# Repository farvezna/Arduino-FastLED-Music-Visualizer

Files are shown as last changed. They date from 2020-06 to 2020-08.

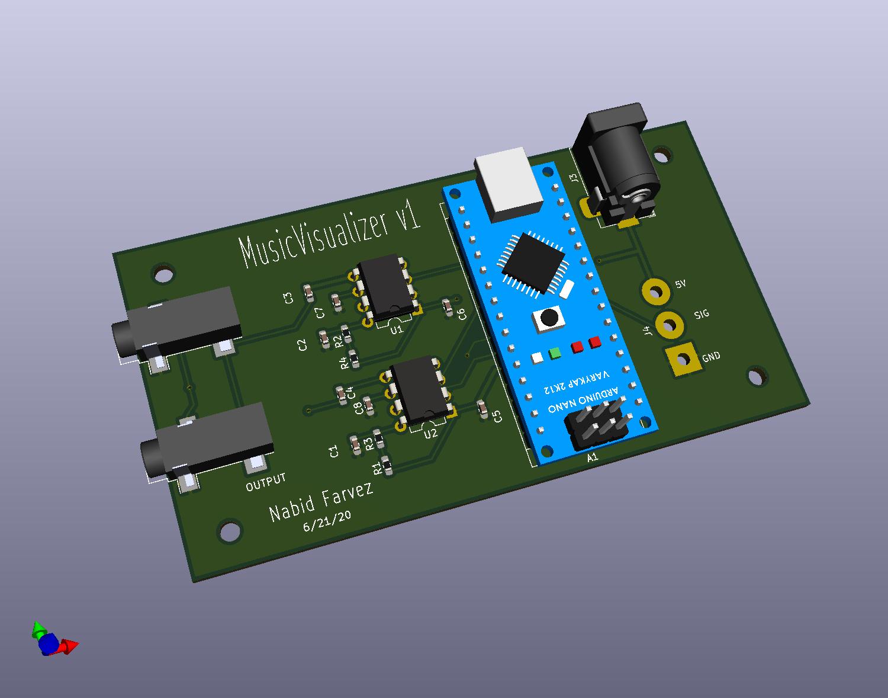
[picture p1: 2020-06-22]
Nabid_PCB/images/Board_render.jpg

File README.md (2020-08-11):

# Arduino FastLED Music Visualizer
NOTE: I created my own PCB to hold an Arduino Nano to gain more practice with PCB layout and soldering through this cool project but all credits to code for RGB lighting are from Just Call Me Koko and the rest of the README below is of his works. The schematic used is essentially a replication of Sparkfun's spectrum shield mentioned below. My contributions are within the Nabid PCB folder.

<p align="center">
  
  <br>
  <a href="https://www.instagram.com/the.red.team4">Instagram</a>
 - <a href="https://www.youtube.com/channel/UCQdi3MDHHMm7u3cMkEY329Q">YouTube</a>
 - <a href="https://208.68.37.54">Website</a>
  <br>
  <br>
  <b>Like my content? Show your support by subscribing to my channel and following my page.</b>
</p>

# Table Of Constituents
- [Intro](#intro)
- [Setup](#setup)
  - [Video Tutorial](https://www.youtube.com/watch?v=Af74A0Tx-wA)
  - [Materials](#materials)
  - [Standalone Arduino UNO Setup](#standalone-arduino-uno-setup)
    - [Code](#code)
    - [Pins](#pins)
  - [Arduino UNO with Sparkfun Spectrum Shield Setup](#arduino-uno-with-sparkfun-spectrum-shield-setup)
    - [Code](#code)
    - [Pins](#pins)

## Intro
An Arduino based music visualizer using the FastLED library and a strip of individually addressable LEDs.  
Imagine this scenario. Does this not make you want to create your own music visualizer?

`> crawled inside of the neighbor's dog`  
`> dog walks inside of neighbor house`  
`> broke into neighbor house by being inside of dog`  
`> it is night now`  
`> brown cow`  
`> creep upstairs to find their mushroom farm`  
`> go into bed room`  
`> nothing`  
`> turn to leave`  
`> emergency yogurt falls out of pocket onto hardwood floor of bedroom`  
`> yogurt everywhere`  
`> wife gets up`  
`> slips on yogurt`  
`> impaled by mattress and is dead`  
`> yogurt murder`  
`> heinous Crims`  
`> power dump on dad's face so he doesn't feel as bad about his dead yogurt wife`  
`> poop yogurt and leave`  
`> poo and yogurt all over`  
`> in the air`  
`> zero gravity and poop`  

I can't find a guide worth a shit on YouTube or Github. I saw many videos showing a demo of a DIY music visualizer using these exact lights and an arduino. People seem to love to brag about how awesome their shit is but they won't show you how to make it. I have created this repo for anyone who faces the same challenge I did. I hope you find this useful and beneficial to your daily intake of fiber.

# Setup
So this is how to setup the most "dank" music visualizer ever.  
There will be two ways to set this puppy up. I prefer the second way, but that costs money.
There is a full video tutorial [here](https://www.youtube.com/watch?v=Af74A0Tx-wA)

## Materials
- [Arduino UNO](https://www.amazon.com/gp/product/B01N4LP86I/ref=oh_aui_detailpage_o06_s00?ie=UTF8&psc=1)
- [WS2812b Individually Addressable LEDs](https://www.amazon.com/gp/product/B01CDTEJBG/ref=oh_aui_detailpage_o09_s00?ie=UTF8&psc=1)
- [Sparkfun Spectrum Shield](https://www.amazon.com/gp/product/B00X0K30I6/ref=oh_aui_detailpage_o07_s00?ie=UTF8&psc=1) (second method)

## Standalone Arduino UNO Setup
### Code
  1. Open [this](https://github.com/the-red-team/Arduino-FastLED-Music-Visualizer/blob/master/music_visualizer.ino) code in your Arduino editor
  2. Line 13, adjust `NUM_LEDS` to the number of LEDs you plan to use
  3. Upload to your Arduino UNO
  
### Pins
  - 5v - Connect to Vcc on LED strip
  - GND - Connect to GND on LED strip
  - A0 - Connect to the other end of the 3.5mm jack connected to your music source
    - A0 must be pulled down with a resistor (shown in the picture below)
  - 6 - Connect to DATA on LED strip
Circuit

## Arduino UNO with Sparkfun Spectrum Shield Setup
For this version of the music visualizer, you will need the [Sparkfun Spectrum Shield](https://www.amazon.com/gp/product/B00X0K30I6/ref=oh_aui_detailpage_o07_s00?ie=UTF8&psc=1)  
I prefer this version because it allows you to split the audio signal into 7 seperate channels (bass, mids, treb). This is important for anyone who wants their music visualizer to respond only to bass like mine.

### Code
  1. Open [this](https://github.com/the-red-team/Arduino-FastLED-Music-Visualizer/blob/master/music_visualizer_sparkfun_spectrum_shield.ino) code in your Arduino IDE
  2. Line 15, adjust `NUM_LEDS` to the number of LEDs you plan to use
  3. Install the FastLED library under "Manage Libraries"
  4. Upload to your Arduino UNO
  
### Pins
  - 5v - Connect to Vcc on LED strip
  - GND - Connect to GND on LED strip
  - 6 - Connect to DATA on LED strip

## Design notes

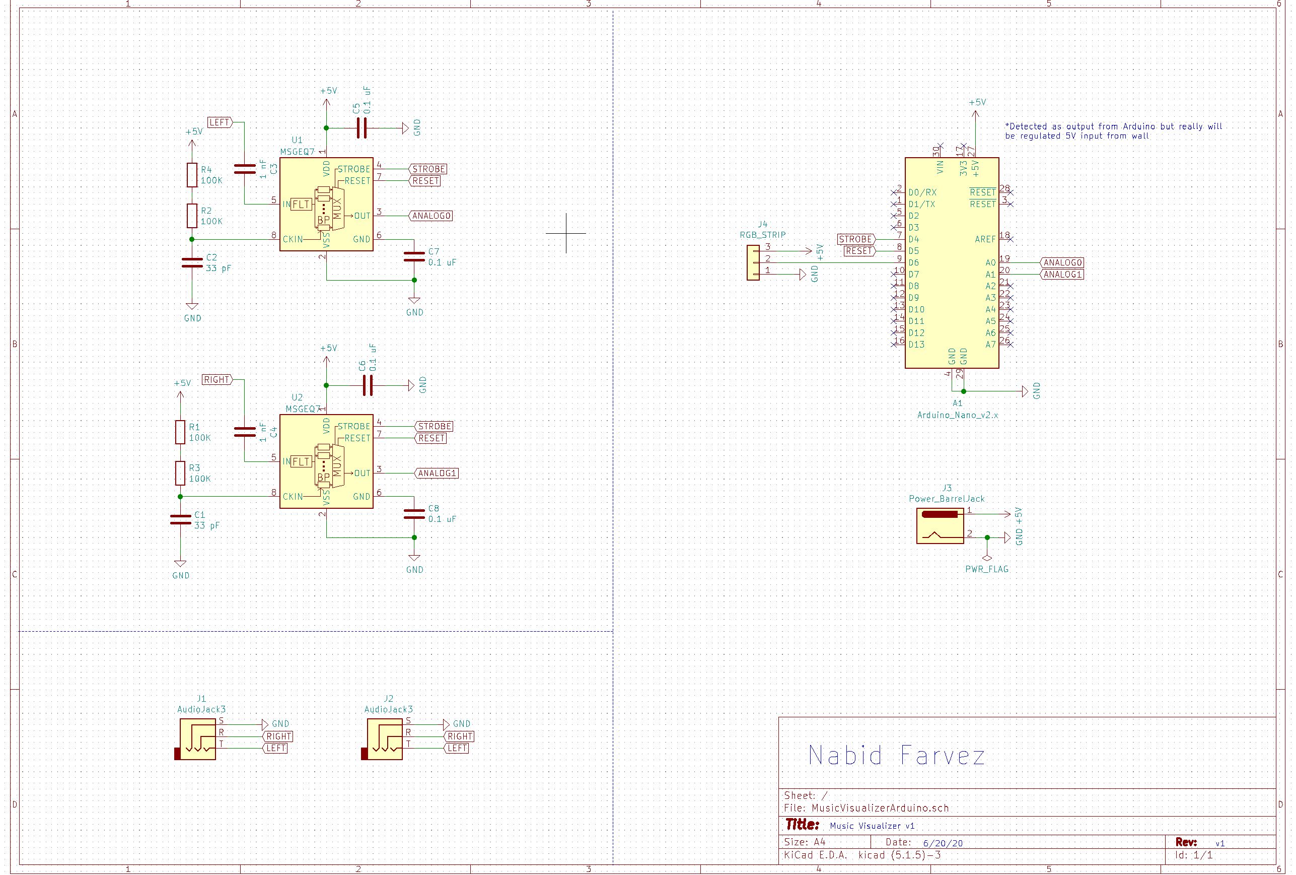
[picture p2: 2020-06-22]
Nabid_PCB/images/Schematic_v1.JPG

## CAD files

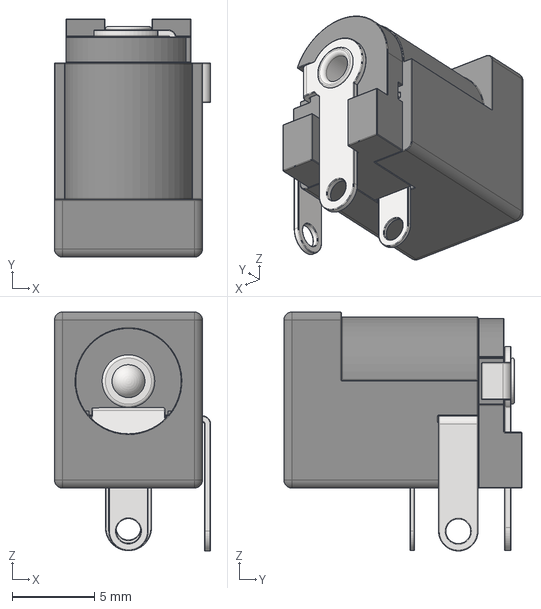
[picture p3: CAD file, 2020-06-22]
Nabid_PCB/3Dmodels/power-barrel-connector-jack-1.snapshot.1/Power Barrel Connector Jack 694106301002.stp
9.49 x 14.5 x 14.5 mm

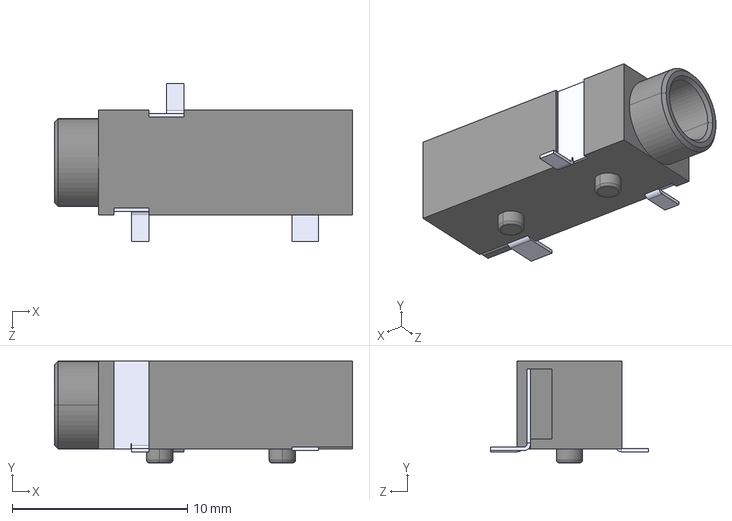
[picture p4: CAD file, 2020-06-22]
Nabid_PCB/3Dmodels/SJ-3523-SMT-TR--3DModel-STEP-56544.STEP
17.0 x 5.80 x 9.00 mm

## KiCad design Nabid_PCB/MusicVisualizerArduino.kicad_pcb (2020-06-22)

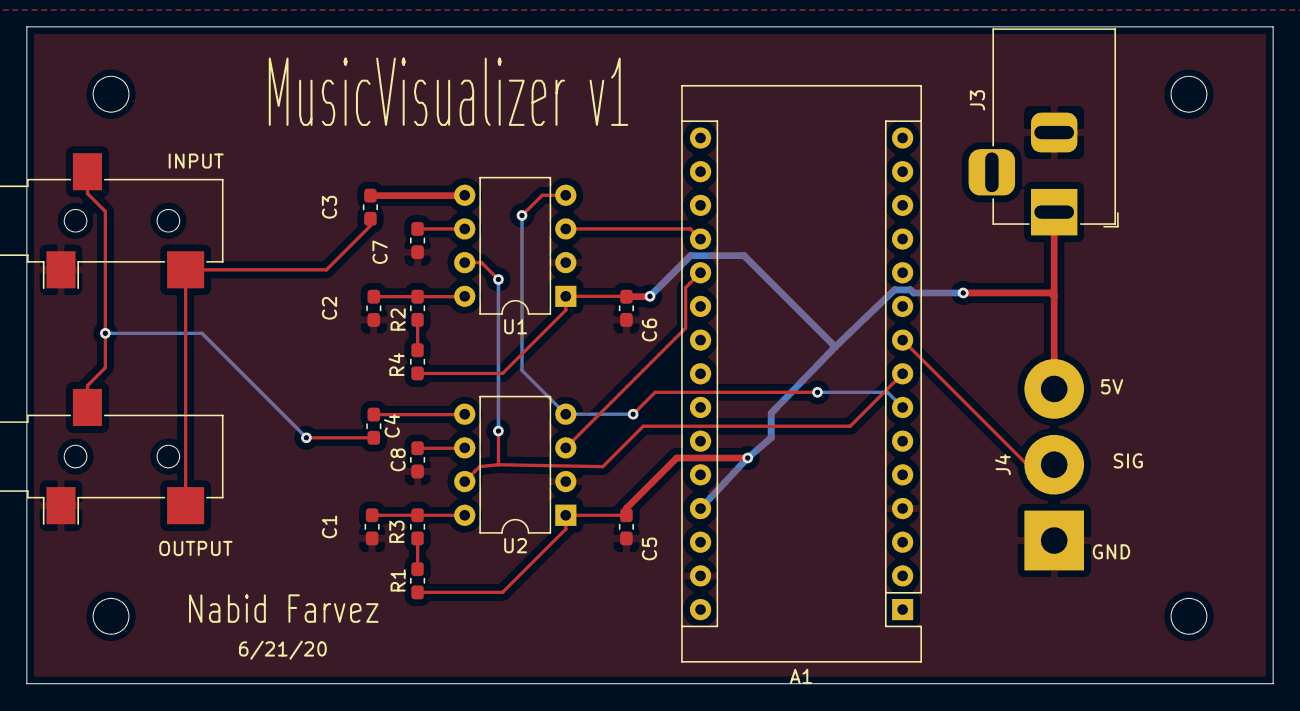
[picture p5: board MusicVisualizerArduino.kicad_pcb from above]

Board: 2 copper layers, 94.0 x 49.5 mm, 19 parts (0 on the bottom side), 17 nets.

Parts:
A1: Arduino_Nano_v2.x; Arduino_Nano
C1, C2: 33 pF; C_0603_1608Metric_Pad1.05x0.95mm_HandSolder
C3, C4: 1 nF; C_0603_1608Metric_Pad1.05x0.95mm_HandSolder
C5, C6, C7, C8: 0.1 uF; C_0603_1608Metric_Pad1.05x0.95mm_HandSolder
INPUT: AudioJack3; Jack_3.5mm_CUI_SJ-3523-SMT_Horizontal
J3: Power_BarrelJack; BarrelJack_Horizontal
J4: RGB_STRIP; SolderWirePad_1x03_P5.715mm_Drill2mm
OUTPUT: AudioJack3; Jack_3.5mm_CUI_SJ-3523-SMT_Horizontal
R1, R2, R3, R4: 100K; R_0603_1608Metric_Pad1.05x0.95mm_HandSolder
U1, U2: MSGEQ7; DIP-8_W7.62mm

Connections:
+5V: A1.27, C5.1, C6.1, J3.1, J4.3, R1.1, R4.1, U1.1, U2.1
ANALOG0: A1.19, U1.3
ANALOG1: A1.20, U2.3
GND: A1.4, A1.29, C1.2, C2.2, C5.2, C6.2, C7.2, C8.1, INPUT.S, J3.2, J4.1, OUTPUT.S, U1.2, U2.2
LEFT: C3.2, INPUT.T, OUTPUT.T
unnamed: A1.9, J4.2
unnamed: C1.1, R3.2, U2.8
unnamed: C2.1, R2.2, U1.8
unnamed: C3.1, U1.5
unnamed: C4.1, U2.5
unnamed: C7.1, U1.6
unnamed: C8.2, U2.6
unnamed: R1.2, R3.1
unnamed: R2.1, R4.2
RESET: A1.8, U1.7, U2.7
RIGHT: C4.2, INPUT.R, OUTPUT.R
STROBE: A1.7, U1.4, U2.4

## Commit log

2020-06-22 added personal PCB design v1
    [MusicVisualizerArduino.kicad_pcb, MusicVisualizerArduino.sch, Power Barrel Connector Jack 694106301002.stp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]
2020-06-22 added pics of schematic and board render
2020-06-22 fixed board cut outline alignment
    [MusicVisualizerArduino.kicad_pcb]
